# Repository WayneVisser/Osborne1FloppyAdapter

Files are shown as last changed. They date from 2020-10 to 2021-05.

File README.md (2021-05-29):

Floppy Adapter for the Osborne 1
--------------------------------

1. The Osborne 1 uses a non-standard Shugart-like floppy interface where +12V and +5V for the drive are
fed through the floppy cable.  This KiCAD project accounts for that and creates a nice tidy 
interface to a GoTek floppy disk emulator.  There is no need to modify the Osborne's floppy cable 
as is the case when using a generic floppy adapter.

2. +5V power for the GoTek is taken from the floppy cable.

3. Jumper only S1 on the GoTek.

4. GoTek part number is: SFR1M44-U100K

5. Connector on adapter to mate with GoTek is a Sullins PPPC172LJBN-RC

6. Program the GoTek with FlashFloppy firmware:  https://github.com/keirf/FlashFloppy

Adapter Pic1

Adapter Pic2

Adapter Pic3

**References**

Electrical Details:

* [vcfed](http://www.vcfed.org/forum/showthread.php?56999-Osborne-1-Gotek-Floppy-Emulator-SUCCESS!)

3D printed 3.5" to 5.25" Floppy Case Adapter:

* [thingverse](https://www.thingiverse.com/thing:2217061)

Richard Loxley has done a lot of good work on the Osborne 1.  His site is a *great* resource for
how to get CP/M-formatted floppy disk images working on the GoTek.

* [Richard Loxley](https://www.richardloxley.com/2018/03/30/retro-challenge-2018-04/)

Just want the board?

* [OSHPark](https://oshpark.com/shared_projects/k4YXJYxn)

Some people report that OSHPark may or may not cut the edge connector slot.  So be prepared to dremmel out the slot yourself if they don't!  Alternatively, it may be easier to remove the key from the floppy cable - just make sure you plug the cable into the adapter correctly or there will be smoke!

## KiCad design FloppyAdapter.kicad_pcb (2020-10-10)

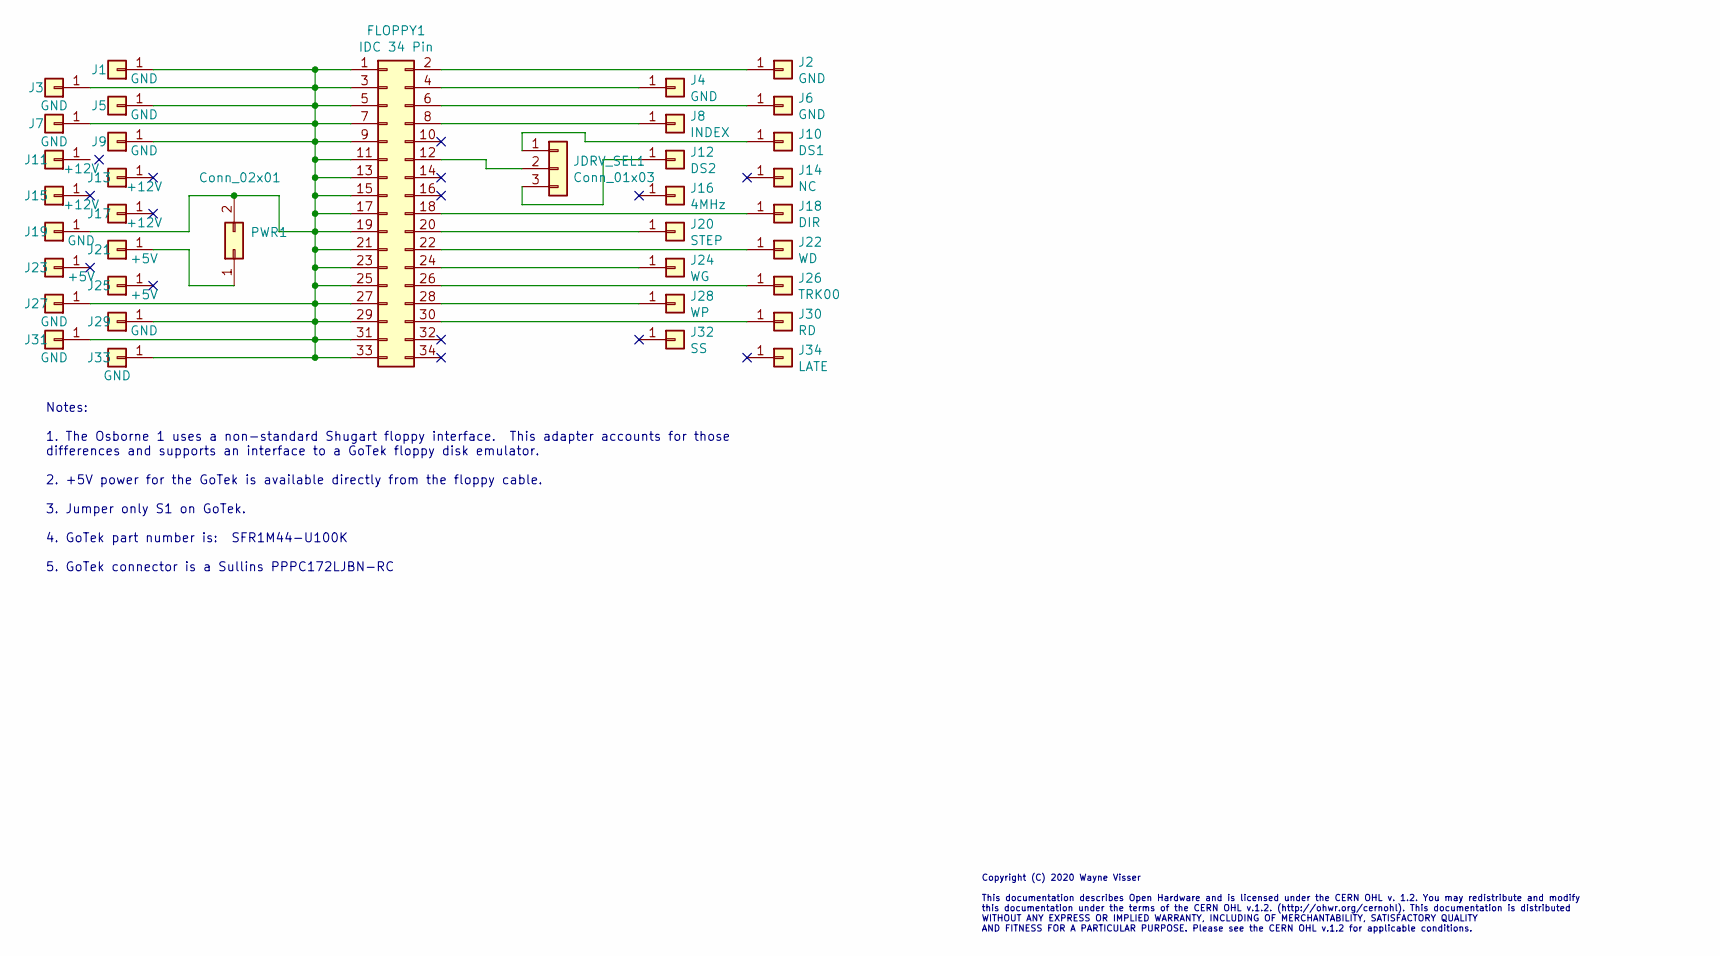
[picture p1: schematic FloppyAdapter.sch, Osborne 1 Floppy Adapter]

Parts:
FLOPPY1: IDC 34 Pin; PPPC172LJBN-RC
J1, J2, J3, J4, J5, J6, J7, J9, J19, J27, J29, J31, J33: GND; EdgeFinger
J8: INDEX; EdgeFinger
J10: DS1; EdgeFinger
J11, J13, J15, J17: +12V; EdgeFinger
J12: DS2; EdgeFinger
J14: NC; EdgeFinger
J16: 4MHz; EdgeFinger
J18: DIR; EdgeFinger
J20: STEP; EdgeFinger
J21, J23, J25: +5V; EdgeFinger
J22: WD; EdgeFinger
J24: WG; EdgeFinger
J26: TRK00; EdgeFinger
J28: WP; EdgeFinger
J30: RD; EdgeFinger
J32: SS; EdgeFinger
J34: LATE; EdgeFinger
JDRV_SEL1: Conn_01x03; Pin_Header_Straight_1x03_Pitch2.54mm
PWR1: Conn_02x01; Pin_Header_Straight_1x02_Pitch2.54mm

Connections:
unnamed 0: FLOPPY1.1, FLOPPY1.3, FLOPPY1.5, FLOPPY1.7, FLOPPY1.9, FLOPPY1.11, FLOPPY1.13, FLOPPY1.15, FLOPPY1.17, FLOPPY1.19, FLOPPY1.21, FLOPPY1.23, FLOPPY1.25, FLOPPY1.27, FLOPPY1.29, FLOPPY1.31, FLOPPY1.33, J1.1, J3.1, J5.1, J7.1, J9.1, J19.1, J27.1, J29.1, J31.1, J33.1, PWR1.2; also elsewhere on the board
unnamed 1: FLOPPY1.2, J2.1; also elsewhere on the board
unnamed 2: FLOPPY1.4, J4.1; also elsewhere on the board
unnamed 3: FLOPPY1.6, J6.1; also elsewhere on the board
unnamed 4: FLOPPY1.8, J8.1; also elsewhere on the board
unnamed 6: FLOPPY1.12, JDRV_SEL1.2; also elsewhere on the board
unnamed 9: FLOPPY1.18, J18.1; also elsewhere on the board
unnamed 10: FLOPPY1.20, J20.1; also elsewhere on the board
unnamed 11: FLOPPY1.22, J22.1; also elsewhere on the board
unnamed 12: FLOPPY1.24, J24.1; also elsewhere on the board
unnamed 13: FLOPPY1.26, J26.1; also elsewhere on the board
unnamed 14: FLOPPY1.28, J28.1; also elsewhere on the board
unnamed 15: FLOPPY1.30, J30.1; also elsewhere on the board
unnamed 18: J10.1, JDRV_SEL1.1; also elsewhere on the board
unnamed 20: J12.1, JDRV_SEL1.3; also elsewhere on the board
unnamed: J21.1, PWR1.1

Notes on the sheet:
Copyright (C) 2020 Wayne Visser This documentation describes Open Hardware and is licensed under the CERN OHL v. 1.2. You may redistribute and modify this documentation under the terms of the CERN OHL v.1.2. (http://ohwr.org/cernohl). This documentation is distributed WITHOUT ANY EXPRESS OR IMPLIED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
Notes: 1. The Osborne 1 uses a non-standard Shugart floppy interface. This adapter accounts for those differences and supports an interface to a GoTek floppy disk emulator. 2. +5V power for the GoTek is available directly from the floppy cable. 3. Jumper only S1 on GoTek. 4. GoTek part number is: S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

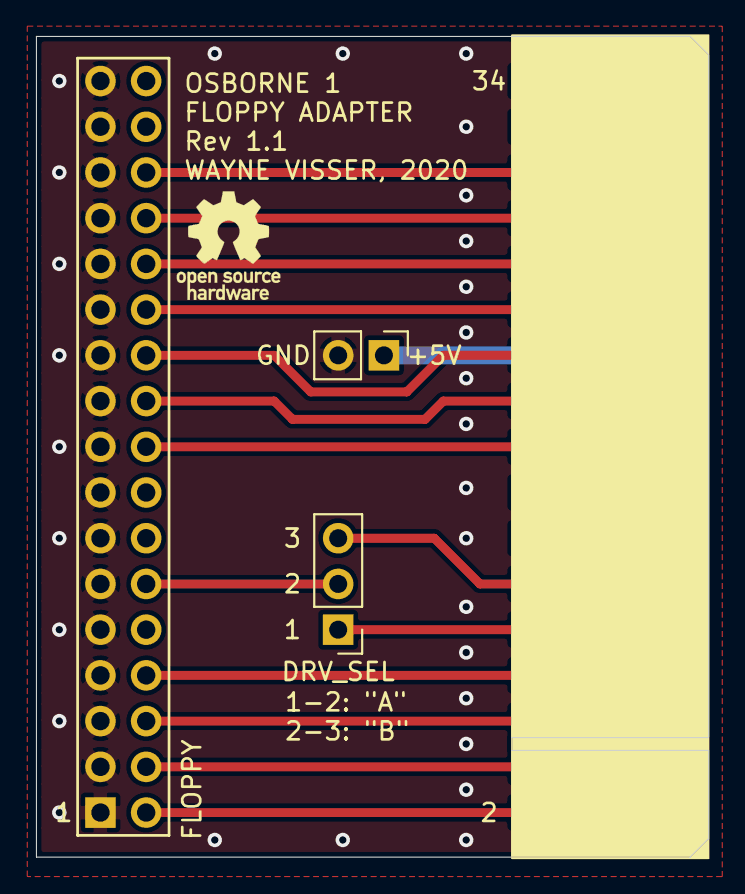
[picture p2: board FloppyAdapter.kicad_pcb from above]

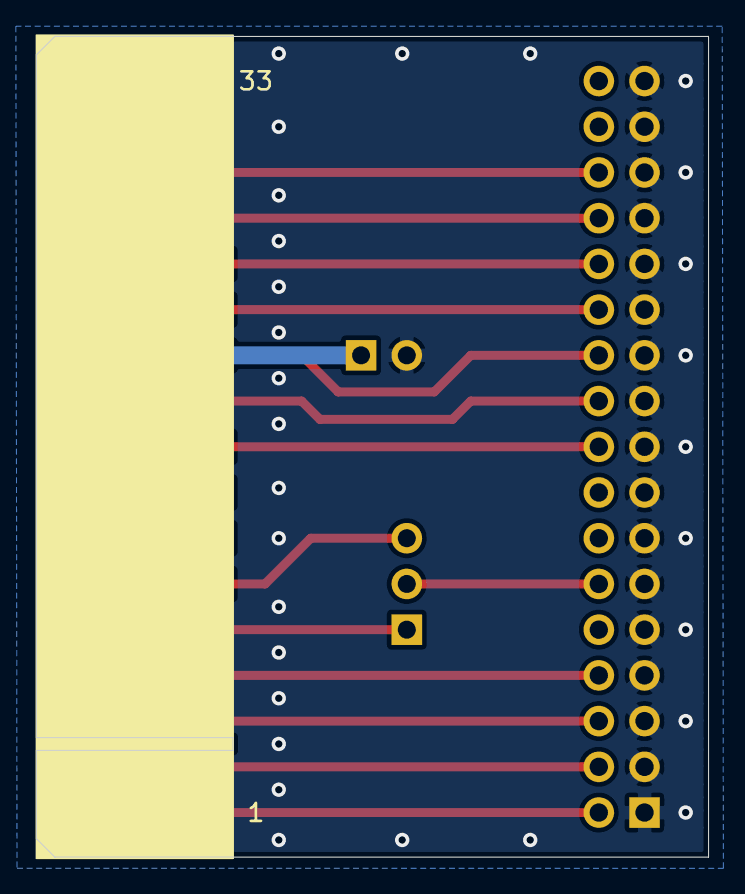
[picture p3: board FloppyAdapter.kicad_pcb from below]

Board: 2 copper layers, 37.3 x 45.6 mm, 37 parts (17 on the bottom side), 16 nets.

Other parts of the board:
DRV_SEL: Conn_01x03; Pin_Header_Straight_1x03_Pitch2.54mm
FLOPPY: IDC 34 Pin; PPPC172LJBN-RC

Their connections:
unnamed 0: FLOPPY.1, FLOPPY.3, FLOPPY.5, FLOPPY.7, FLOPPY.9, FLOPPY.11, FLOPPY.13, FLOPPY.15, FLOPPY.17, FLOPPY.19, FLOPPY.21, FLOPPY.23, FLOPPY.25, FLOPPY.27, FLOPPY.29, FLOPPY.31, FLOPPY.33; also elsewhere on the board
unnamed 1: FLOPPY.2; also elsewhere on the board
unnamed 2: FLOPPY.4; also elsewhere on the board
unnamed 3: FLOPPY.6; also elsewhere on the board
unnamed 4: FLOPPY.8; also elsewhere on the board
unnamed 6: DRV_SEL.2, FLOPPY.12; also elsewhere on the board
unnamed 9: FLOPPY.18; also elsewhere on the board
unnamed 10: FLOPPY.20; also elsewhere on the board
unnamed 11: FLOPPY.22; also elsewhere on the board
unnamed 12: FLOPPY.24; also elsewhere on the board
unnamed 13: FLOPPY.26; also elsewhere on the board
unnamed 14: FLOPPY.28; also elsewhere on the board
unnamed 15: FLOPPY.30; also elsewhere on the board
unnamed 18: DRV_SEL.1; also elsewhere on the board
unnamed 20: DRV_SEL.3; also elsewhere on the board

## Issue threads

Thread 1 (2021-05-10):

Boards from Oshpark don't have the board cutout

agentbooth, 2021-05-10:
I ordered a set of your (awesome) boards from Oshpark, but they don't have the slot cutout. It looks like since the cutout is on the "board outline" layer, it might not be supported. It says that drill cutouts need to be on the Drills layer.

From Oshpark:
`Slots are unsupported when indicated on the board outline layer, but usually work. To make slots with full support, use Drill Slots on the drill layer.`

agentbooth, 2021-05-23:
I just noticed my floppy connector on Drive B wasn't keyed, so I guess the slot isn't needed (?)
